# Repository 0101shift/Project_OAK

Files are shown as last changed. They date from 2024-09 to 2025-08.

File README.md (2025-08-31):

# ⌚️ Project OAK (Open Art Work)

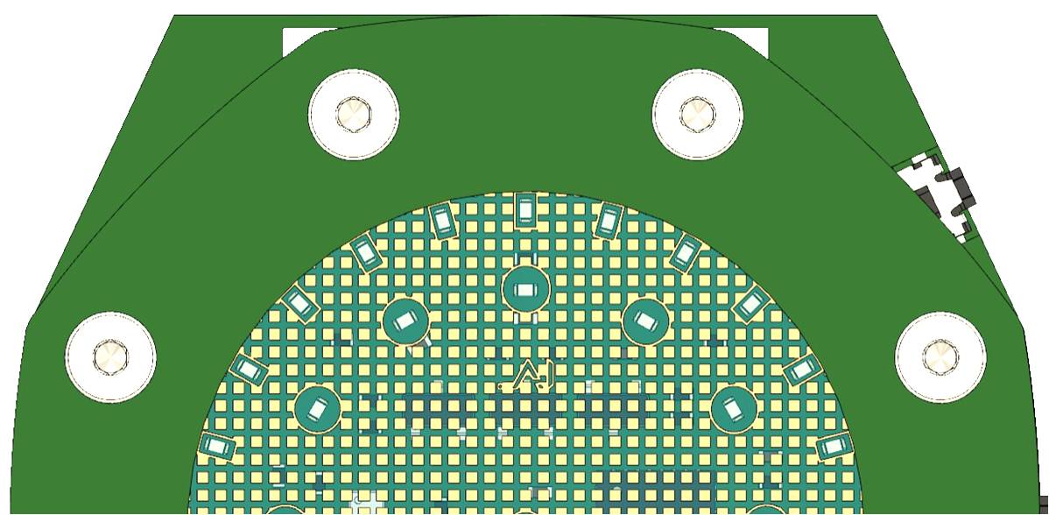
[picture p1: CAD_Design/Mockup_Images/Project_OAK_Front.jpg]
Project OAK

> *An approach to mimic analogue watch complications in a digital timepiece. One LED at a time.*

> ⚠️ **_Current Version: v0.1_**

> 📝 [_Version History_](Design/LLD_Design/README.md)
---

## 📁 Repository Overview

This repository contains all files related to **Project OAK**, including:

- Design files
- Datasheets
- Pin configuration sheet
- BOM (Bill of Materials)
- Source code and libraries
- Mechanical Integration files

📎 **Project OAK SCH and DSN files can be viewed on [CADLAB.io](https://cadlab.io/project/28412)**

---

## 📖 Project Overview

**Project_OAK** explores a different approach to designing digital timepieces that mimic the beauty and intricacy of **[mechanical watch complications](https://teddybaldassarre.com/blogs/watches/watch-complications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)**.

While building a digitalised analogue-style watch is fairly common, recreating some of the mechanical features in a purely digital watch is both challenging and exciting.

> Although current smartwatches offer these functions via complex hardware, my goal is to **implement them using simple hardware** with minimal processing power.

- To add to its uniqueness, the **entire watch will be constructed using stacked PCBs**, which is aimed to be modular and reconfigurable based on our needs.
- The watch is designed with multiple colours and solder finishes, giving it a true electronics-nerd feel.

---

## 🎲 How it Works

> "V0.1 / V0.2" come with a simple design to set and view the time. Here’s an infographic that shows the process

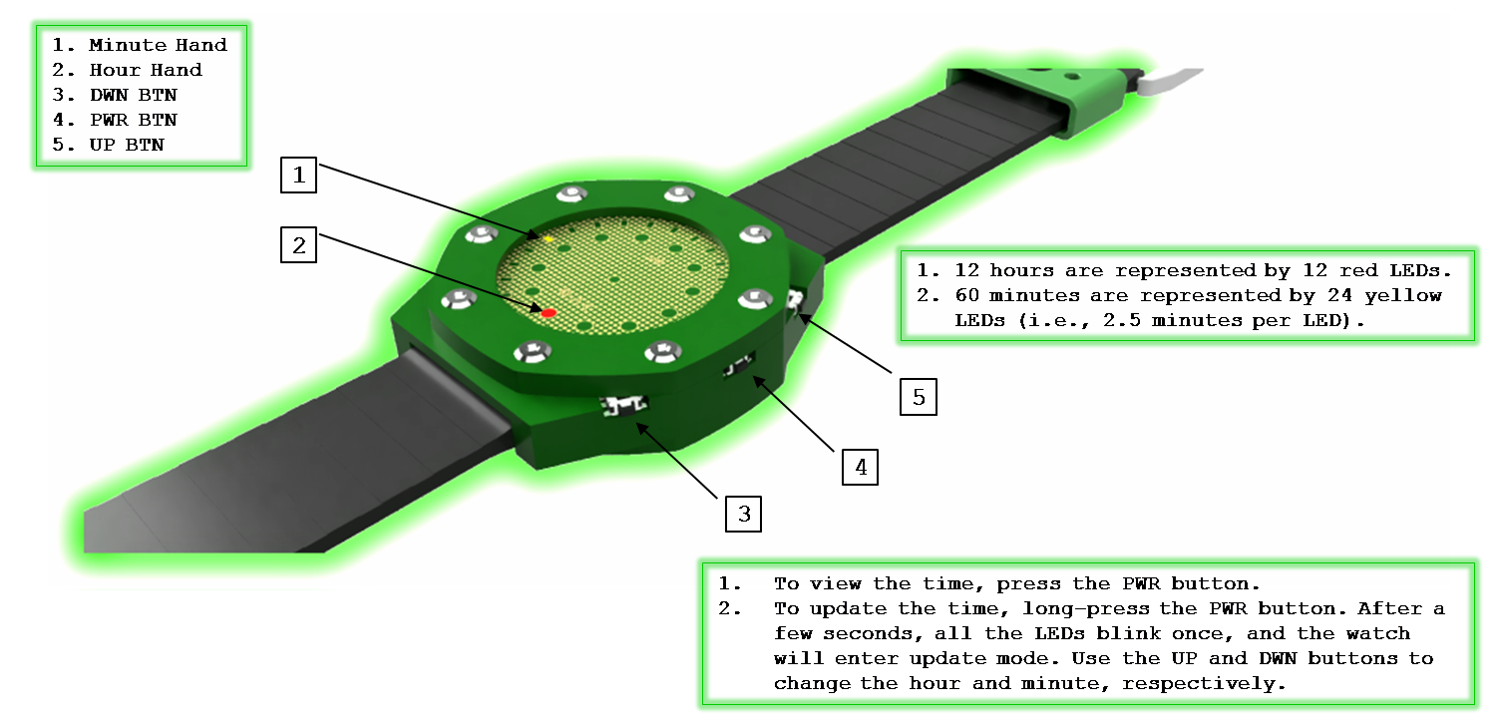
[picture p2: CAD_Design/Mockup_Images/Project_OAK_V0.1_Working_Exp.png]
V0.1 working


---

## 🔧 Initial Prototype

📌 **[Project_OAK_MAIN_BRD_V0.1 / V0.2](Design/LLD_Design/V0.1/Project_OAK_MAIN_BRD_V0.1_RTC_Change/Project_OAK_MAIN_BRD_V0.1.pdf) is an "engineering sample".**

The primary goal of these variants is to **test all available interfaces, validate battery performance, identify design flaws, and iterate for improvements**.

Consider this board a creative playground, push its limits and explore unique feature additions for the upcoming revision.

---

## 🚀 Down the line

Though the **initial version** of Project_OAK (V0.1 / V0.2) is just a simple watch featuring a **time display** using dual-tone LEDs,

> The Future versions shall include:
> - GMT
> - Minute Repeater (ambitious!)
> - Interactive sensors (Light, IMU, Temp, Step tracking, Buzzer, etc.)
> - Higher-density LED matrix for complex visuals.
> - Position tracking using GPS, LoRa, etc. (ambitious!)
> - Exploring Low-power MCUs for long-life operation.
> - Rechargeable battery option.
> - Solar panel integration for energy harvesting.
> - ...

---

## 💎 Mechanical Integration (v0.1)

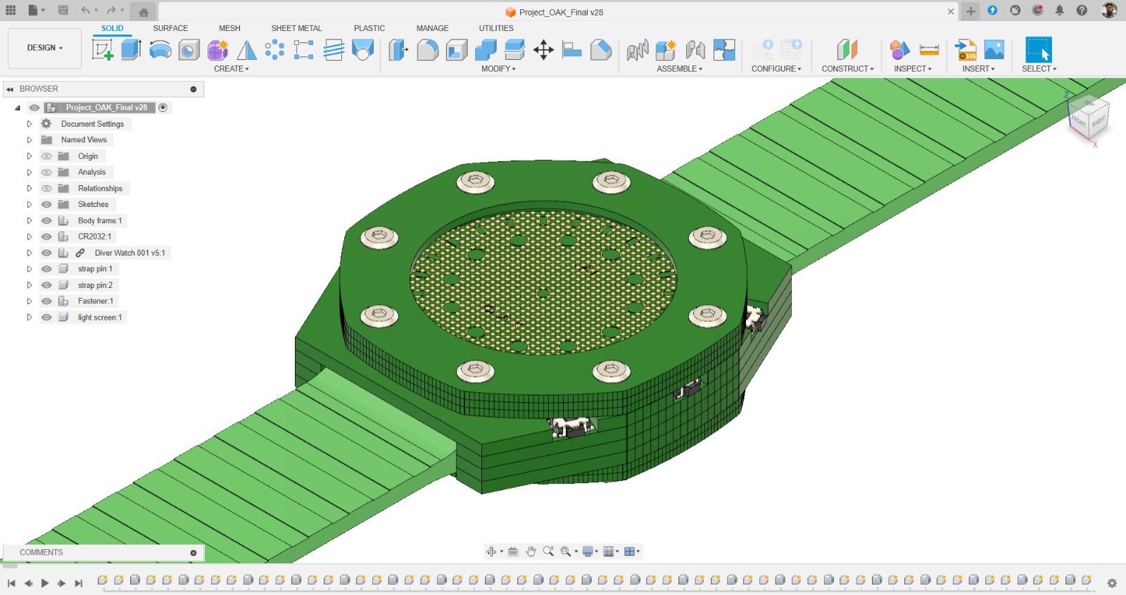
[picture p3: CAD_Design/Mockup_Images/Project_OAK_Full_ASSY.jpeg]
Initial Mockup


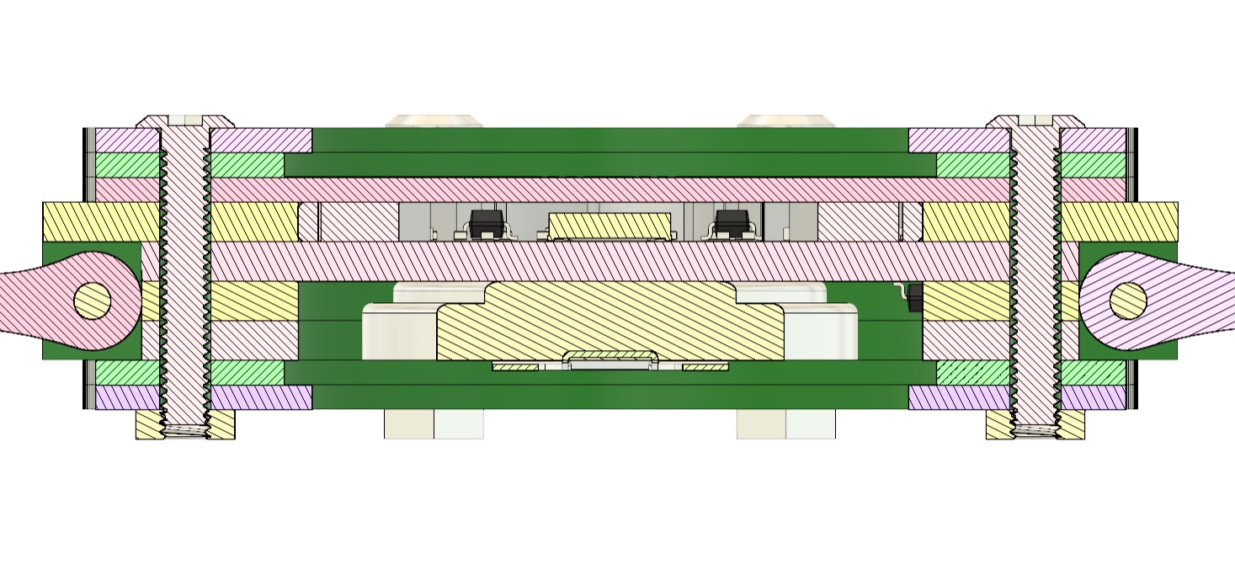
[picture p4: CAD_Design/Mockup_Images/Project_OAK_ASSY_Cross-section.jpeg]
Cross-section View


Exploded View

Exploded View

> *(These are the outputs from V0.1 variant. Design changes are expected in V0.2)*

---

## ⚙️ Getting Started

### 🔌 Programming the Board

The board can be programmed using the **Arduino IDE** via the ISP function. All the source code can be found in [ProjectOAK/codes](Codes) folder. 

#### 📝 Requirements:
- Arduino UNO/MINI/NANO/MEGA as ISP programmer
- ICSP connection to the Main Board (test points on the bottom side)

#### 💡 ICSP Programming Notes:
- ICSP pins are exposed via **Test Points** arranged in 2.4mm pitch 2x3 connector style
- Either mount **male headers** or directly solder wires for programming
- Board supports **two power options**:
  - `3V Coin Cell (default)`
  - `EXT_3V3_IN` via ICSP (requires mounting resistor R1, which is **DNI by default**)

### ⚡ Arduino IDE Settings

> - Refer to this GitHub repo on how to burn the Bootloader and how to flash code through Arduino IDE [MiniCore](https://github.com/MCUdude/MiniCore)
> - When programming the MAIN_BRD, update the ARDUINO IDE settings as shown below.

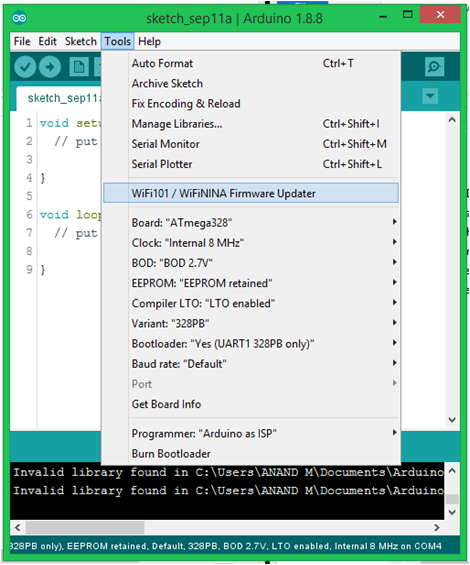
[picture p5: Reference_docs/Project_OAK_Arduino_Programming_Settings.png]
Arduino IDE settings


#### ❤️‍🔥 Let me know what you think of this project. I'd love to hear your thoughts!

### ✨ Happy Designing!

---

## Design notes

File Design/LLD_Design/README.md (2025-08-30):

# 📚 Version History

## 🔮 V0.2 (Engineering Sample2 - Planned)
- Button circuit connectivity update
- Remove the transistor configuration from the LED matrix directly. Direct connection is simple.
- Battery monitoring circuit implementation (possibly).
- Push button components to be moved towards the inner circle to avoid mechanical collision.
- Top Silk graphics to be removed from the main board.
- Main board & BOT cavity PCB dimension to be increased in Y-direction, to match the STARP V0 board dimension
- 0E to be replaced with solder-jumpers in the LED matrix section
- DNPed MCU UART resistors
  
## 🔰 V0.1 (Engineering Sample - WIP)
- RTC changed from RX8130CE to RV-8263-C7.
- Addressed design issues with rework on the main board. Rework is documented in: [Project_OAK_MAIN_BRD_V0.1_Rework](Reworks/V0.1/README.md). 
- Cell voltage monitoring (along with LED indication) is not implemented in V0.1. Planned for V0.2
- Final testing in progress.

 <div style="background-color:#ffe6e6; padding:10px; border-radius:6px;">
⚠️ <b>Caution:</b> Other layers, except the Main Board, are reused from V0
</div>

## 🚫 V0 (Initial Design - Unreleased)
- Initial board design consists of ATmega328PB MCU, RX8130CE RTC, 36 LEDs (12H + 24M) & 2032 coin cell holder  
- The design was not released for fabrication due to a change in the RTC module.

---

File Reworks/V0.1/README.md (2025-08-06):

# 🔧 Project OAK MAIN BRD V0.1 Rework

This document outlines the necessary fixes, design limitations, and manual rework instructions for **Version 0.1** of the main board.

## 📋 Includes:
- Design errors identified during testing
- Workarounds and hardware patches
- Recommended changes for future revisions

> ⚠️ These instructions are critical if you're testing or building with `Project_OAK_MAIN_BRD_V0.1`.

---

## ❌ Design Errors

- The **BC547 transistor** symbol used in the design (V0 / V0.1) was of **TO-92 type**, while the actual **PCB footprint was for SOT-type**. This caused pin mismatch and made the footprint incompatible.
  
- The **push-button connection** was incorrect. It was connected between **pin 1 & pin 2** in the schematic, whereas the correct connection should be **between pin 1 & pin 3**. This made the switch unresponsive as pin 2 was shorted between GND and VCC via the 10k resistor.

---

## 🔶 Workaround for Transistor

- Since the BC547 pinout issue can't be resolved easily on the PCB, better to:
  - **Remove the transistor**, and  
  - **Short the Base and Emitter pins**.  
    This gives direct control of the LEDs to the MCU, and the firmware has been adjusted accordingly.

> 🔧 Additionally:
> - Remove the **resistor connected to the Collector pin**, as it will be left floating after the transistor is removed.
> - Reduce the **Base resistor value to 560Ω or less**, allowing sufficient current flow from the LEDs to the MCU.

---

## 🔶 Workaround for Push-Button

To make the push-button functional:
- Remove the **external pull-up resistor** (the internal pull-up is sufficient).
- Carefully **cut the trace between pin 2 and GND** to isolate pin 2. *(This can be tricky but is necessary.)*
- Connect **pin 3 to GND** using a short jumper wire.

---

## ✔️ V0.1 Rework Instructions

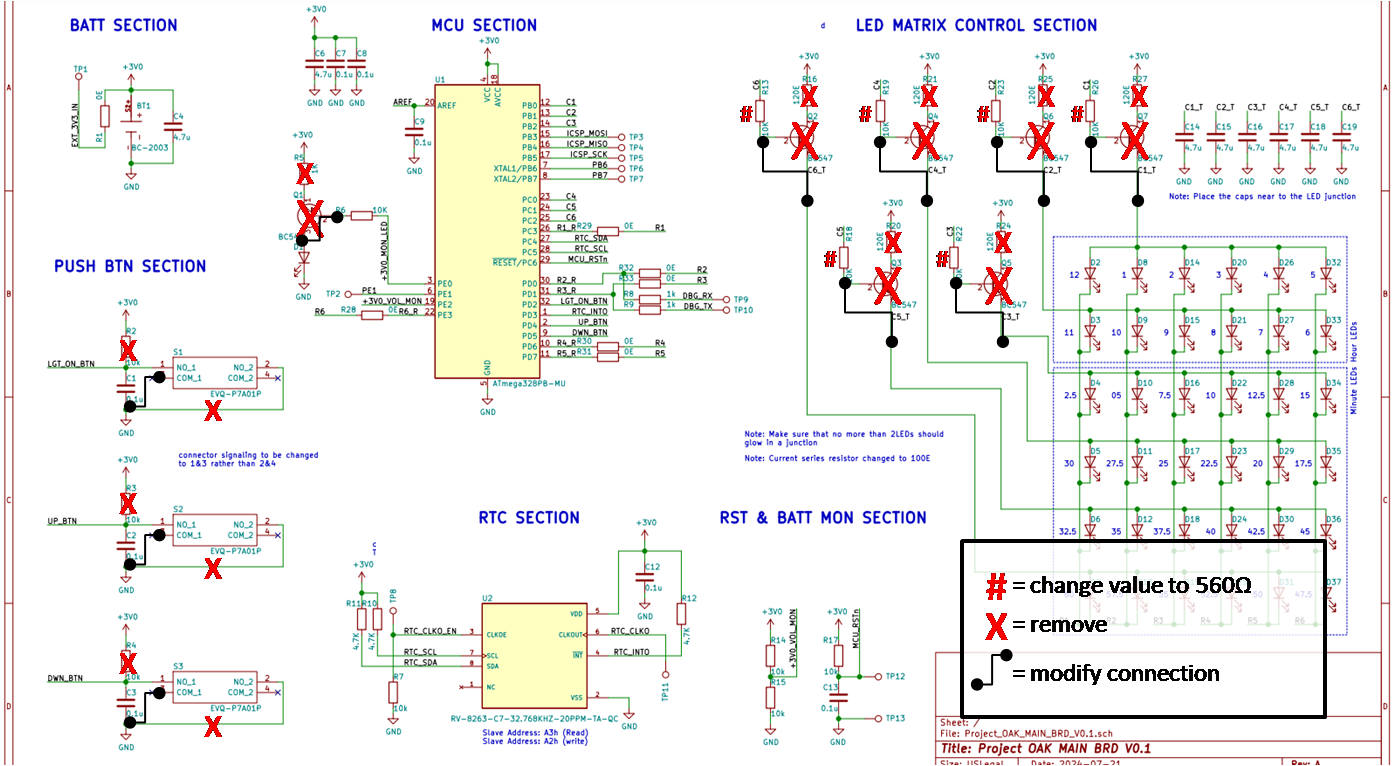
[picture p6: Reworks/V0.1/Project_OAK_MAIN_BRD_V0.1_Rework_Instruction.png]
Project_OAK_MAIN_BRD_V0.1_Rework


---

## 📌 Recommendations for Future Revisions

- **Remove the transistors** in the LED section entirely:
  - The LED matrix draws low current and can be driven directly by the MCU.
  - This also helps reduce BOM cost and simplifies the layout.
  
- **Double-check all component footprints and connections** to avoid similar pin mismatch issues.

---

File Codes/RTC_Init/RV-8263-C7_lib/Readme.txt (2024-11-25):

Place the lib files present in src folder into Arduino libraries 
folder before compiling the code

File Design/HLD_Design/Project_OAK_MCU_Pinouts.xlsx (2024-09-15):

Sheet: Pin_Mapping
ATMEGA328PB-MU Pin mapping |  |  |  |  |  |  |  |  | Available GPIOs: | 27
S. No | Pin Name | Pin Type | Pin Functions |  |  |  | Functions Assigned | Destination | Used GPIOs: | 24
 |  |  | Default | Alt1 | Alt2 | Alt3 |  |  | Excess GPIOs: | 3
1 | PD[3] | GPIO | IO | INT1 | OC2B |  | INTERRUPT | RTC
2 | PD[4] |  | IO | T0 |  |  | INPUT | BTN
3 | PE[0] |  | IO | ACO | ICP4 | SDA1 | IO | BAT MON LED
4 | VCC | POWER
5 | GND
6 | PE[1] | GPIO | IO | T4 | SCL1 |  | IO | Future use
7 | PB[6] | CLOCK |  | XTAL1/TOSC1
8 | PB[7] |  |  | XTAL2/TOSC2
9 | PD[5] | GPIO | IO | OC0B / T1 |  |  | INPUT | BTN
10 | PD[6] |  |  | AIN0 | OC0A |  | IO | LED MTRX CTRLx
11 | PD[7] |  |  | AIN1
12 | PB[0] |  |  | CLKO | ICP1
13 | PB[1] |  |  | OC1A
14 | PB[2] |  |  | OC1B | SS0
15 | PB[3] |  |  | OC2A | TXD1 | MOSI0 | SPI | ICSP
16 | PB[4] |  |  | RXD1 | MISO0
17 | PB[5] |  |  | XCK1 | SCK0
18 | AVCC | POWER
19 | PE[2] | GPIO | IO | ADC6 | ICP3 | SS1 | ADC | BAT VOL MON
20 | AREF | ANALOG POWER
21 | GND | POWER
22 | PE[3] | GPIO | IO | ADC7 | T3 | MOSI1 | IO | LED MTRX CTRLx
23 | PC[0] |  |  | ADC0 | MISO1
24 | PC[1] |  |  | ADC1 | SCK1
25 | PC[2] |  |  | ADC2
26 | PC[3] |  |  | ADC3
27 | PC[4] |  |  | ADC4 | SDA0 |  | I2C | RTC
28 | PC[5] |  |  | ADC5 | SCL0
29 | PC[6] | RESET
30 | PD[0] | GPIO | IO | OC3A | RXD0 |  | UART / IO | LED MTRX CTRLx + UART DEBUG
31 | PD[1] |  |  | OC4A | TXD0
32 | PD[2] |  |  | INT0 | OC3B / OC4B |  | INTERRUPT | BTN

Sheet: LED_Mapping
WATCH DIAL LED Mapping
S. No | Row | Column | Row Pin | Column Pin | LED Type | LED Value
1 | C1 | R1 | PB0 | PC3 | Hour | 12
2 | C1 | R2 | PB0 | PD0 | Hour | 1
3 | C1 | R3 | PB0 | PD1 | Hour | 2
4 | C1 | R4 | PB0 | PD6 | Hour | 3
5 | C1 | R5 | PB0 | PD7 | Hour | 4
6 | C1 | R6 | PB0 | PE3 | Hour | 5
7 | C2 | R1 | PB1 | PC3 | Hour | 11
8 | C2 | R2 | PB1 | PD0 | Hour | 10
9 | C2 | R3 | PB1 | PD1 | Hour | 9
10 | C2 | R4 | PB1 | PD6 | Hour | 8
11 | C2 | R5 | PB1 | PD7 | Hour | 7
12 | C2 | R6 | PB1 | PE3 | Hour | 6
13 | C3 | R1 | PB2 | PC3 | Minute | 2.5
14 | C3 | R2 | PB2 | PD0 | Minute | 5
15 | C3 | R3 | PB2 | PD1 | Minute | 7.5
16 | C3 | R4 | PB2 | PD6 | Minute | 10
17 | C3 | R5 | PB2 | PD7 | Minute | 12.5
18 | C3 | R6 | PB2 | PE3 | Minute | 15
19 | C4 | R1 | PC0 | PC3 | Minute | 30
20 | C4 | R2 | PC0 | PD0 | Minute | 27.5
21 | C4 | R3 | PC0 | PD1 | Minute | 25
22 | C4 | R4 | PC0 | PD6 | Minute | 22.5
23 | C4 | R5 | PC0 | PD7 | Minute | 20
24 | C4 | R6 | PC0 | PE3 | Minute | 17.5
25 | C5 | R1 | PC1 | PC3 | Minute | 32.5
26 | C5 | R2 | PC1 | PD0 | Minute | 35
27 | C5 | R3 | PC1 | PD1 | Minute | 37.5
28 | C5 | R4 | PC1 | PD6 | Minute | 40
29 | C5 | R5 | PC1 | PD7 | Minute | 42.5
30 | C5 | R6 | PC1 | PE3 | Minute | 45
31 | C6 | R1 | PC2 | PC3 | Minute | 0
32 | C6 | R2 | PC2 | PD0 | Minute | 57.5
33 | C6 | R3 | PC2 | PD1 | Minute | 55
34 | C6 | R4 | PC2 | PD6 | Minute | 52.5
35 | C6 | R5 | PC2 | PD7 | Minute | 50
36 | C6 | R6 | PC2 | PE3 | Minute | 47.5

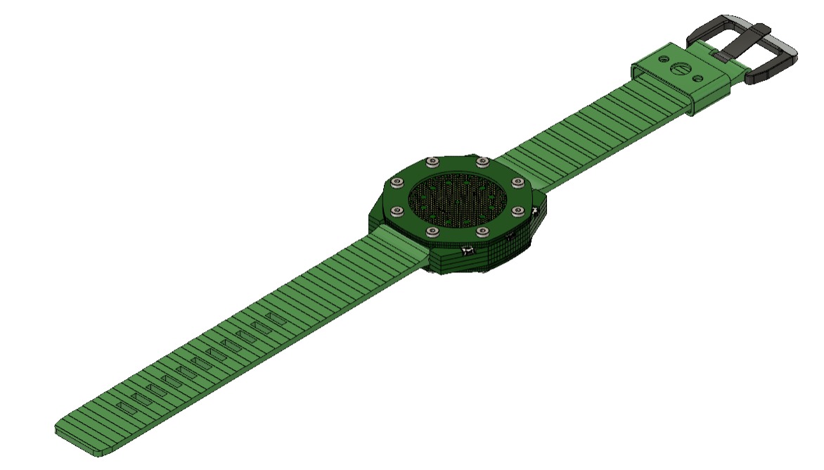
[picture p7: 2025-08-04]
CAD_Design/Mockup_Images/Project_OAK_Full_ASSY_1.jpeg

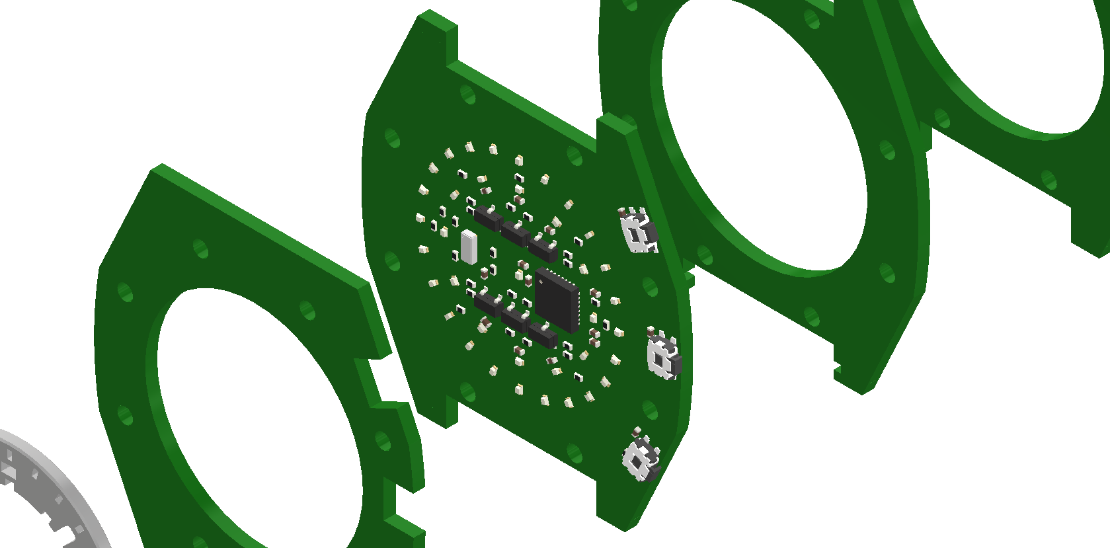
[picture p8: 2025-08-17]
CAD_Design/Mockup_Images/Project_OAK_Exploded_view.png

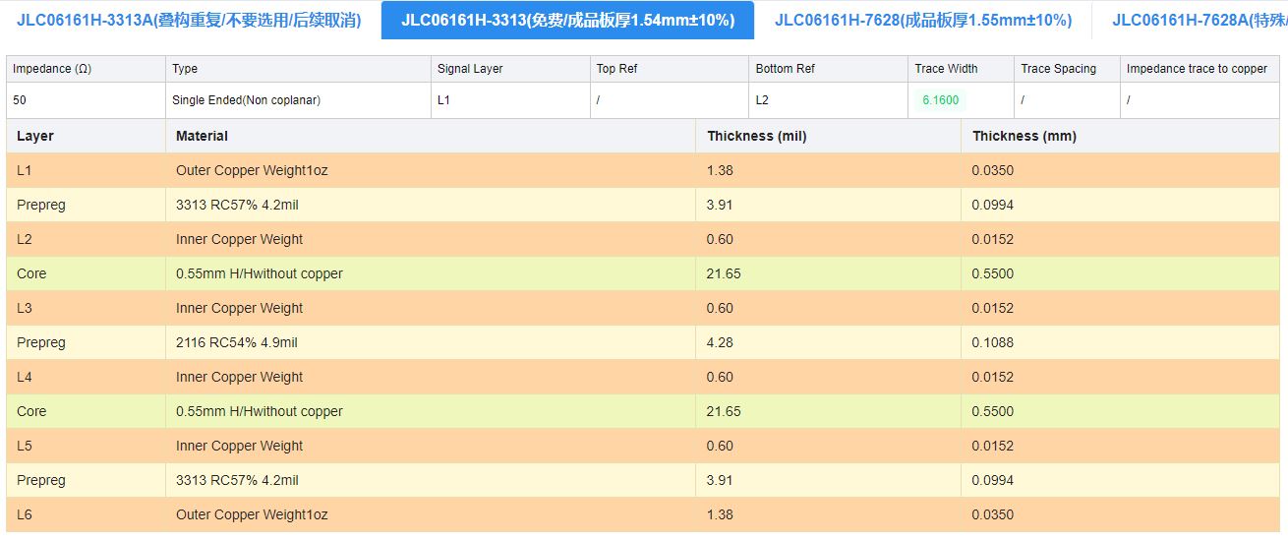
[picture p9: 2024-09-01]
CAD_Design/PCB_CAD/6L_JLCPCB_Stackup.JPG

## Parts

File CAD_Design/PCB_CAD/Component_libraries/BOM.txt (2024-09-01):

1. DS3231MZ+TRL / RX8130CE / RX8111CE
 / RV-8263-C7-32.768KHZ-20PPM-TA-QC -> RTC module
2. PKLCS1212E4001-R1 -> buzzer
3. BC-2003 -> SMD battery holder
4. EVQ-P7A01P -> Tactle switch
5. ATMEGA328P-MMHR / ATMEGA328PB-MNR / ATMEGA328PB-MU / ATMEGA328PB-AU-> MCU

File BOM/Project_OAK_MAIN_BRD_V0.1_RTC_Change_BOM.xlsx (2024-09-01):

Qty | Ref. Desg. | Value | Description | MFR PN | MFR | JLCPCB PN | Footprint | Assembly Instruction
1 | BT1 | BC-2003 |  |  |  |  | Battery:BAT_BC-2003 | DNP
8 | C1, C2, C3, C7, C8, C9, C12, C13 | 0.1u | 16V 100nF X7R ±10% 0402 Multilayer Ceramic Capacitors MLCC - SMD/SMT ROHS | GCM155R71C104KA55J | Murata Electronics | C2655418 | Capacitor_SMD:C_0402_1005Metric
1 | C4 | 4.7u |  |  |  |  |  | DNP
7 | C6, C14, C15, C16, C17, C18, C19 | 4.7u | 6.3V 4.7uF X5R ±20% 0402 Multilayer Ceramic Capacitors MLCC - SMD/SMT ROHS | C1005X5R0J475MTJ00E | TDK | C23687 | Capacitor_SMD:C_0402_1005Metric
25 | D1, D4, D5, D6, D7, D10, D11, D12, D13, D16, D17, D18, D19, D22, D23, D24, D25, D28, D29, D30, D31, D34, D35, D36, D37 | Yellow LED | Yellow 592nm LED Indication - Discrete 2V 0402 (1005 Metric) | LTST-C281KSKT | Lite-On Inc. | C913108 | LED_SMD:LED_0402_1005Metric
12 | D2, D3, D8, D9, D14, D15, D20, D21, D26, D27, D32, D33 | Red LED | Red 0402 LED Indication - Discrete ROHS | 16-213/R6C-AQ2R2B/3T | Everlight Elec | C264407 | LED_SMD:LED_0402_1005Metric
7 | Q1, Q2, Q3, Q4, Q5, Q6, Q7 | BC547 |  |  |  |  | Package_TO_SOT_SMD:SOT-23 | DNP
7 | R1, R28, R29, R30, R31, R32, R33 | 0E |  |  |  |  | Resistor_SMD:R_0402_1005Metric | DNP
1 | R1 | 0E |  |  |  |  | Resistor_SMD:R_0402_1005Metric | DNP
14 | R2, R3, R4, R6, R7, R14, R15, R17, R13, R18, R19, R22, R23, R26 | 10k | 63mW Thick Film Resistors ±100ppm/℃ ±5% 10kΩ 0402 Chip Resistor | CR0402J10K0Q10Z | Ever Ohms Tech | C881063 | Resistor_SMD:R_0402_1005Metric
3 | R5, R8, R9 | 1K |  |  |  |  | Resistor_SMD:R_0402_1005Metric | DNP
3 | R10, R11, R12 | 4.7K | 62.5mW ±1% 4.7kΩ 0402 Chip Resistor - Surface Mount ROHS | RMC04024K7FN | TyoHM | C270129 | Resistor_SMD:R_0402_1005Metric
6 | R16, R20, R21, R24, R25, R27 | 100E | 62.5mW Thick Film Resistors 50V ±100ppm/℃ ±0.5% 100Ω 0402 Chip Resistor - Surface Mount ROHS | RM04DTN1000 | TA-I Tech | C187947 | Resistor_SMD:R_0402_1005Metric
3 | S1, S2, S3 | EVQ-P7A01P | Black Side Tactile Switch, Single Pole Single Throw (SPST) 50 mA @ 12 V dc 1.7mm | EVQ-P7A01P | Panasonic | EVQP7A01P | Button_Switch_SMD:EVQP7J01P
1 | U1 | ATmega328PB-MU | 32KB 1.8V~5.5V AVR 2KB 20MHz FLASH 27 QFN-32-EP(5x5) Microcontrollers (MCU/MPU/SOC) ROHS | ATmega328PB-MU | Microchip | C967933 | Package_DFN_QFN:QFN-32-1EP_5x5mm_P0.5mm_EP3.1x3.1mm
1 | U2 | RV-8263-C7-32.768KHZ-20PPM-TA-QC | I2C SON-8(1.5x3.2) Real Time Clocks ROHS | RV-8263-C7-32.768KHZ-20PPM-TA-QC | Micro Crystal | C5138246 | Crystal:RV-8263-C7-32.768KHZ-20PPM-TA-QC

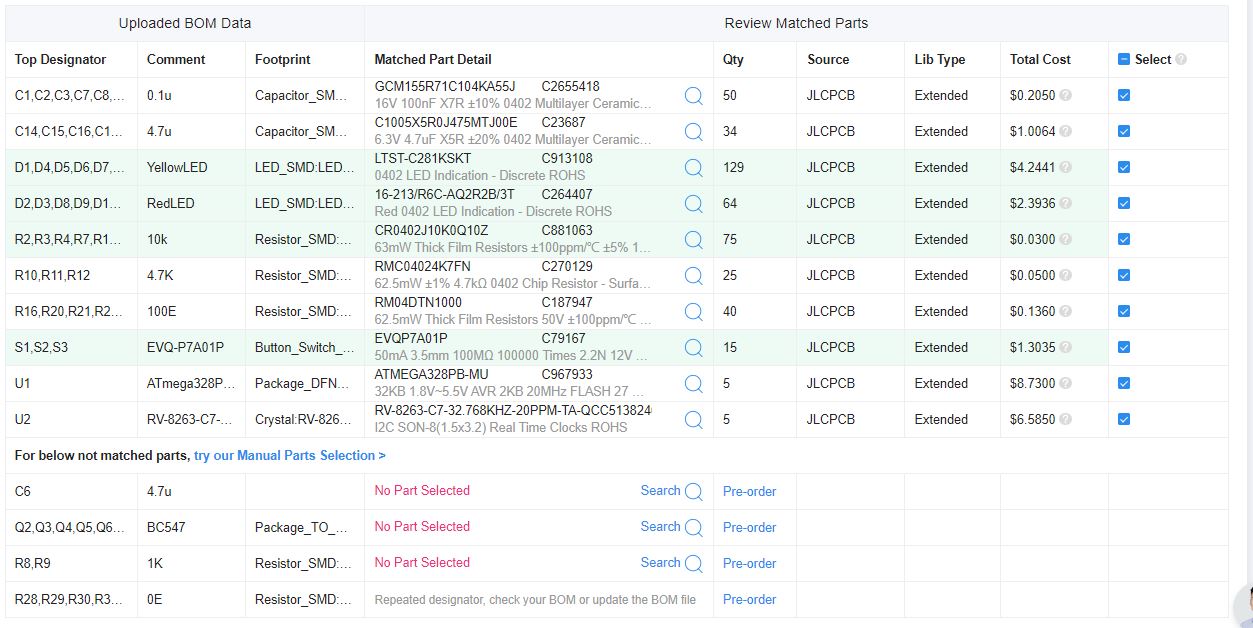
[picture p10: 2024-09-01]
BOM/Project_OAK_MAIN_BRD_V0.1_RTC_Change_JLCPCB_Final_BOM.JPG

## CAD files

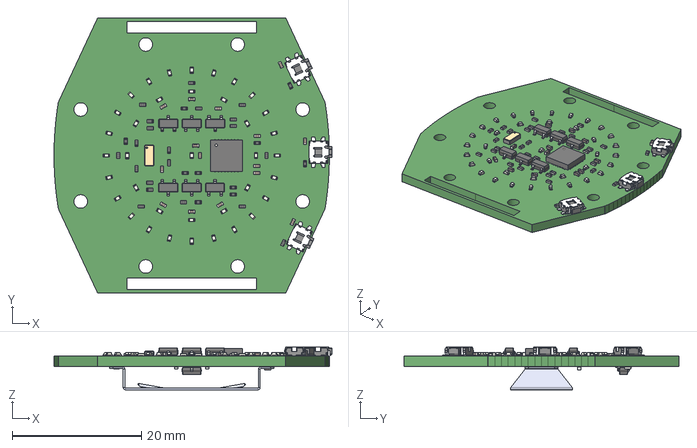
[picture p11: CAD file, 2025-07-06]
Design/LLD_Design/V0.1/Project_OAK_MAIN_BRD_V0.1_RTC_Change/Project_OAK_MAIN_BRD_V0.1.step
43.0 x 42.6 x 6.59 mm

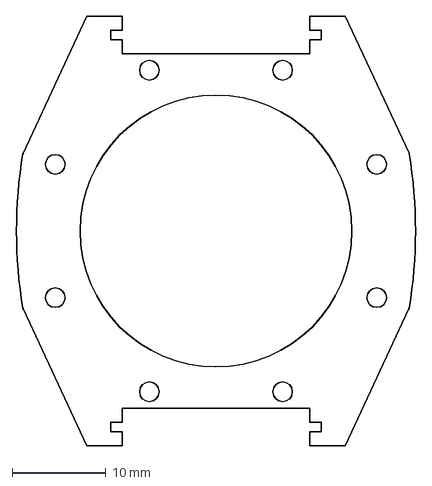
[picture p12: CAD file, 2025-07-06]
CAD_Design/Mechanical_CAD/PROJECT_OAK_BOT_STRAP.dxf
42.6 x 45.8 mm

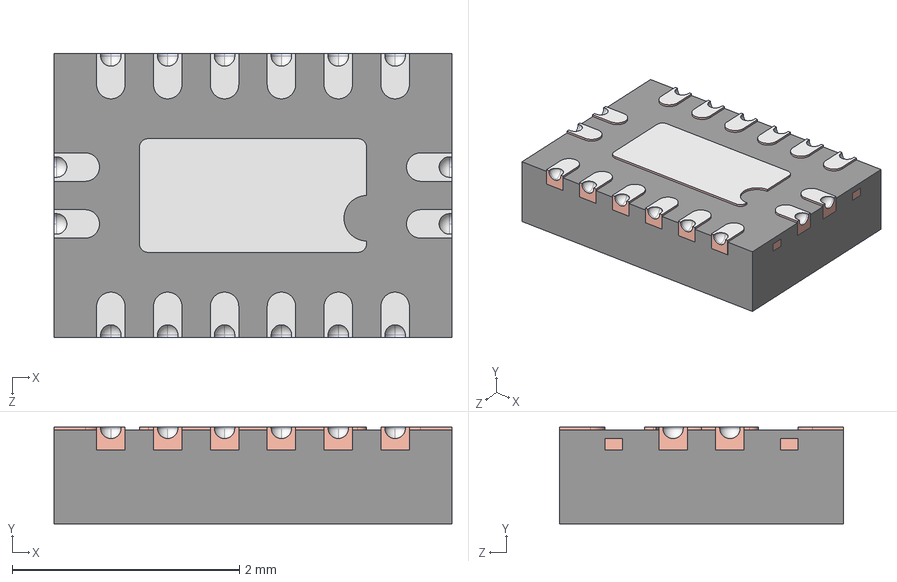
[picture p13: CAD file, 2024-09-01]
CAD_Design/PCB_CAD/Component_libraries/74CBTLV3257BQ,115/3D/74CBTLV3257BQ,115.stp
3.50 x 0.85 x 2.50 mm
SOT763-1 LF
SOT763-1 Mold Body

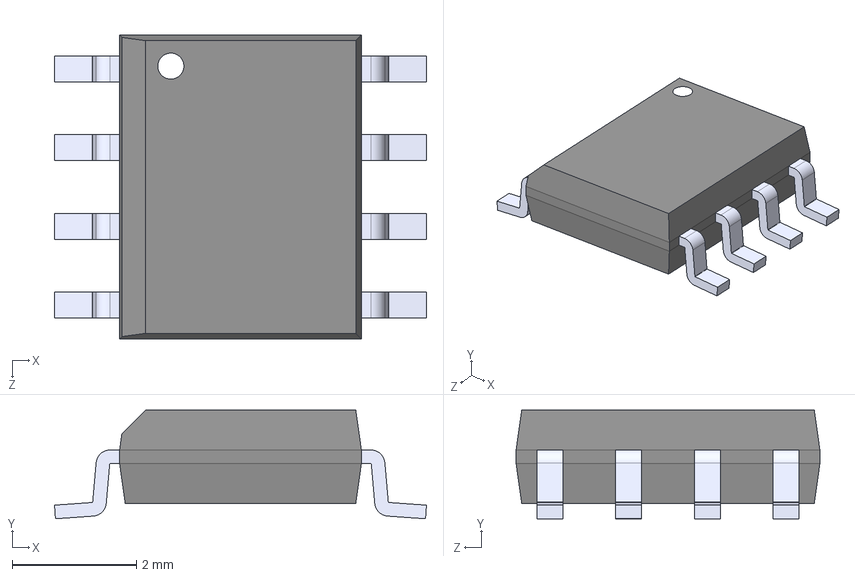
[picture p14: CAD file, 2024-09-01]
CAD_Design/PCB_CAD/Component_libraries/DS3231MZ_TRL/DS3231MZ_TRL.step
6.00 x 1.75 x 4.90 mm

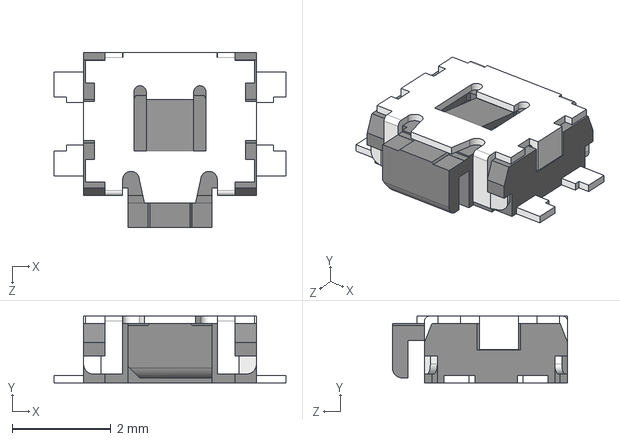
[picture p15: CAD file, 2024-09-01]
CAD_Design/PCB_CAD/Component_libraries/EVQ-P7A01P/3D/EVQ-P7A01P.stp
4.70 x 1.35 x 3.55 mm

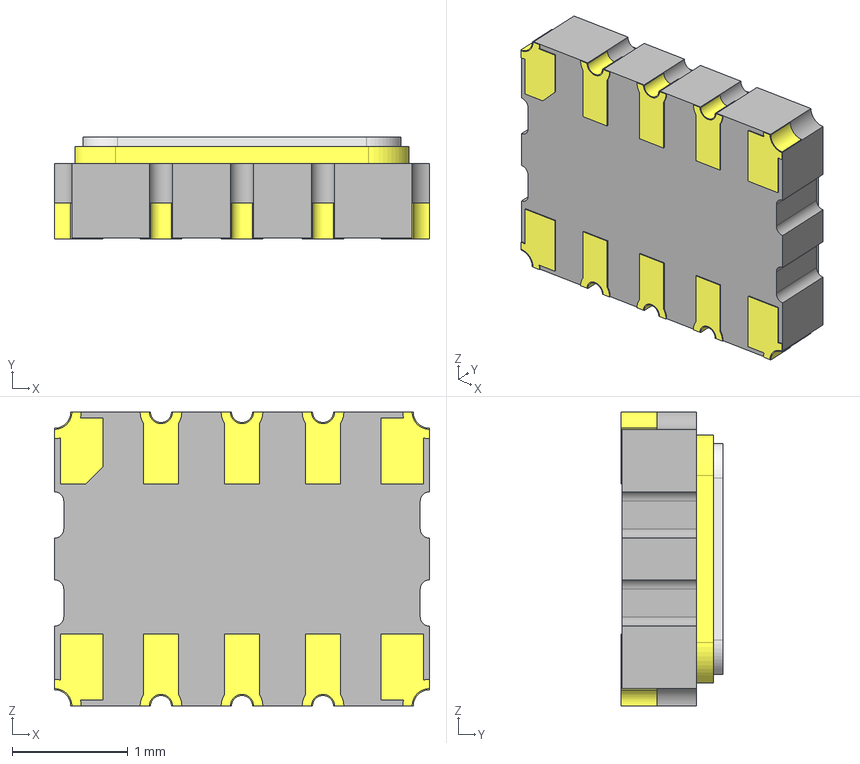
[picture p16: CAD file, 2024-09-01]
CAD_Design/PCB_CAD/Component_libraries/RX8130CE/RX8130CE.stp
3.24 x 0.88 x 2.54 mm
CERAMIC_1_1_2
____-______O__1_6__1_1_2
____-______O__1_5__1_1_2
____-______O__1_10__1_1_2
____-______O__1_7__1_1_2
____-______O__1_3__1_1_2
____-______O__1_4__1_1_2
____-______O__1_1__1_1_2
____-______O__1_2__1_1_2
____-______O__1_9__1_1_2
____-______O__1_8__1_1_2
SRING_1_1_2
LID0001_1_1_2

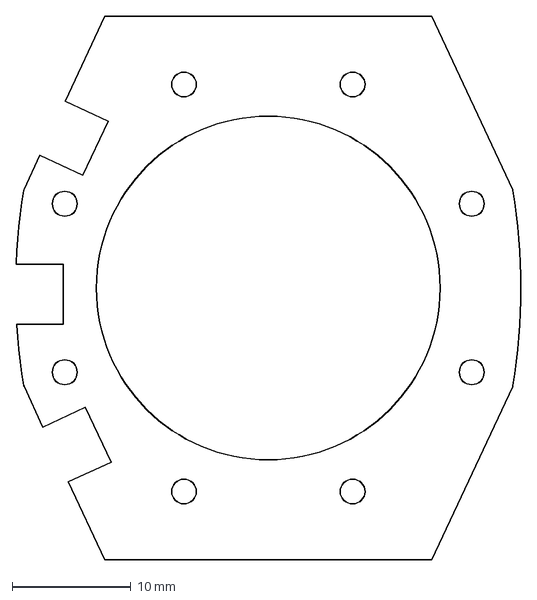
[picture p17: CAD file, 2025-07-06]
CAD_Design/Mechanical_CAD/PROJECT_OAK_TOP_LED_CAVITY.dxf
42.6 x 45.8 mm

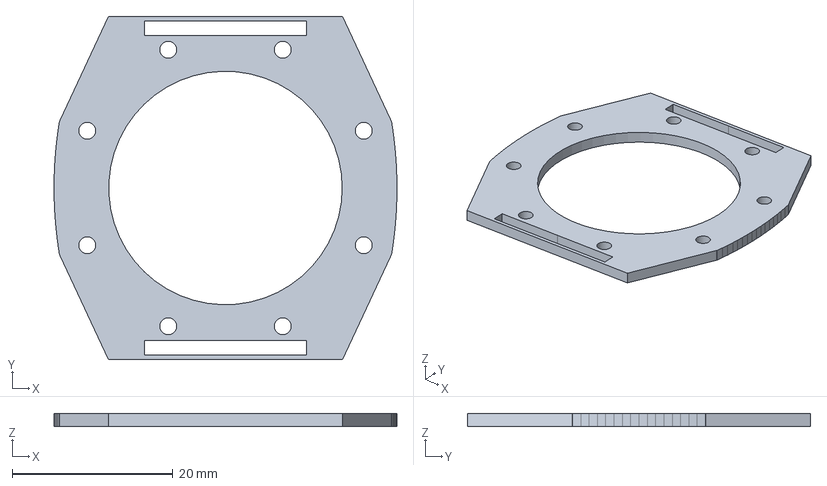
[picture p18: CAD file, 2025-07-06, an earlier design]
Design/LLD_Design/V0/Project_OAK_BOT_CAVITY_V0/Project_OAK_BOT_CAVITY_V0.step
42.6 x 42.6 x 1.60 mm

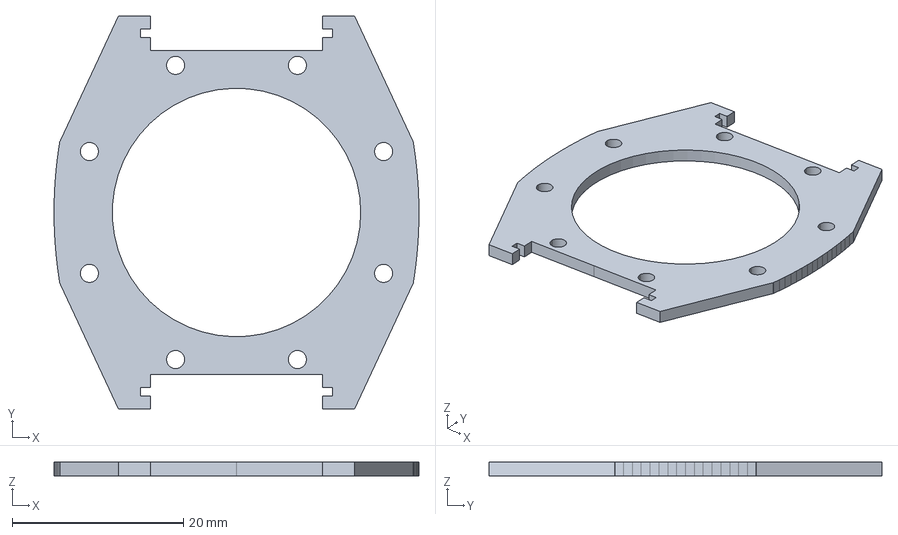
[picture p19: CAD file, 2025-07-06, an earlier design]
Design/LLD_Design/V0/Project_OAK_BOT_STRAP_V0/Project_OAK_BOT_STRAP_V0.step
42.6 x 45.8 x 1.60 mm

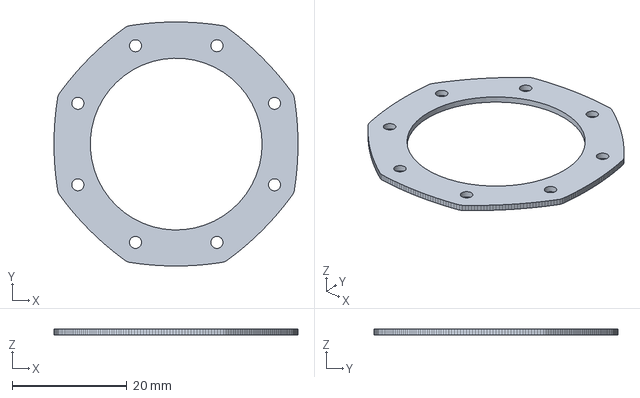
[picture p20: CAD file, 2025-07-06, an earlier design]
Design/LLD_Design/V0/Project_OAK_HEX_COVER_INNER_V0/Project_OAK_HEX_COVER_INNER_V0.step
42.6 x 42.6 x 1.00 mm

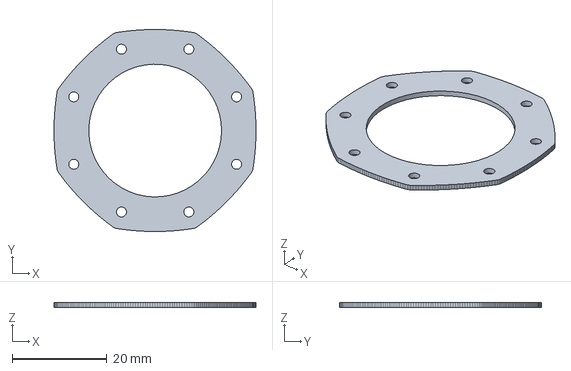
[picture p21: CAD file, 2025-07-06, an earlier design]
Design/LLD_Design/V0/Project_OAK_HEX_COVER_OUTER_V0/Project_OAK_HEX_COVER_OUTER_V0.step
42.6 x 42.6 x 1.00 mm

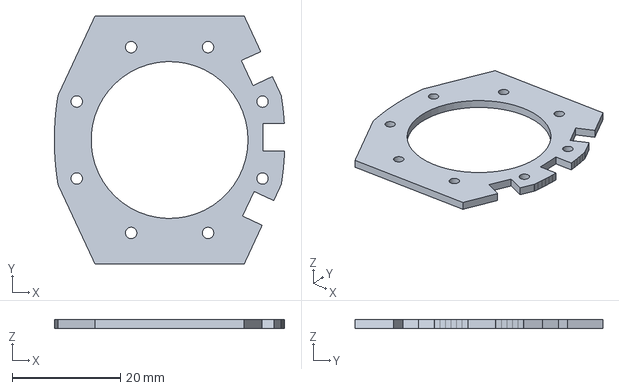
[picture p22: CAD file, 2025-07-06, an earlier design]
Design/LLD_Design/V0/Project_OAK_TOP_LED_CAVITY_V0/Project_OAK_TOP_LED_CAVITY_V0.step
42.6 x 45.8 x 1.60 mm

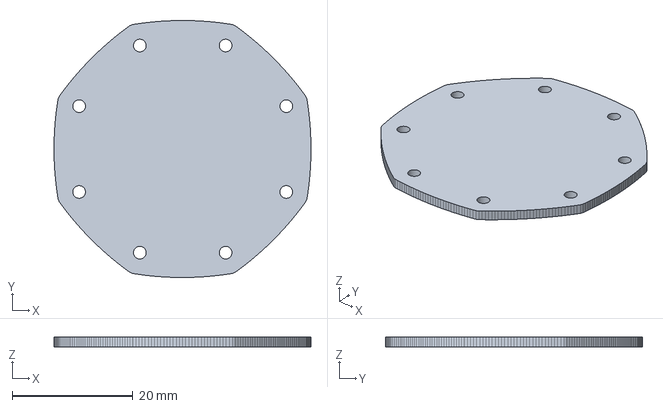
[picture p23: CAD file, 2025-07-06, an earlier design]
Design/LLD_Design/V0/Project_OAK_WATCH_DIAL_V0/Project_OAK_WATCH_DIAL_V0.step
42.6 x 42.6 x 1.60 mm

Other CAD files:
CAD_Design/PCB_CAD/Component_libraries/74CBTLV3257BQ,115/Allegro/74hct595bq115.psm
CAD_Design/PCB_CAD/Component_libraries/74CBTLV3257BQ,115/DEHDL/74cbtlv3257bq_115/chips/chips.prt
CAD_Design/PCB_CAD/Component_libraries/EVQ-P7A01P/Allegro/evqp7j01p.psm
CAD_Design/PCB_CAD/Component_libraries/EVQ-P7A01P/DEHDL/evq_p7a01p/chips/chips.prt

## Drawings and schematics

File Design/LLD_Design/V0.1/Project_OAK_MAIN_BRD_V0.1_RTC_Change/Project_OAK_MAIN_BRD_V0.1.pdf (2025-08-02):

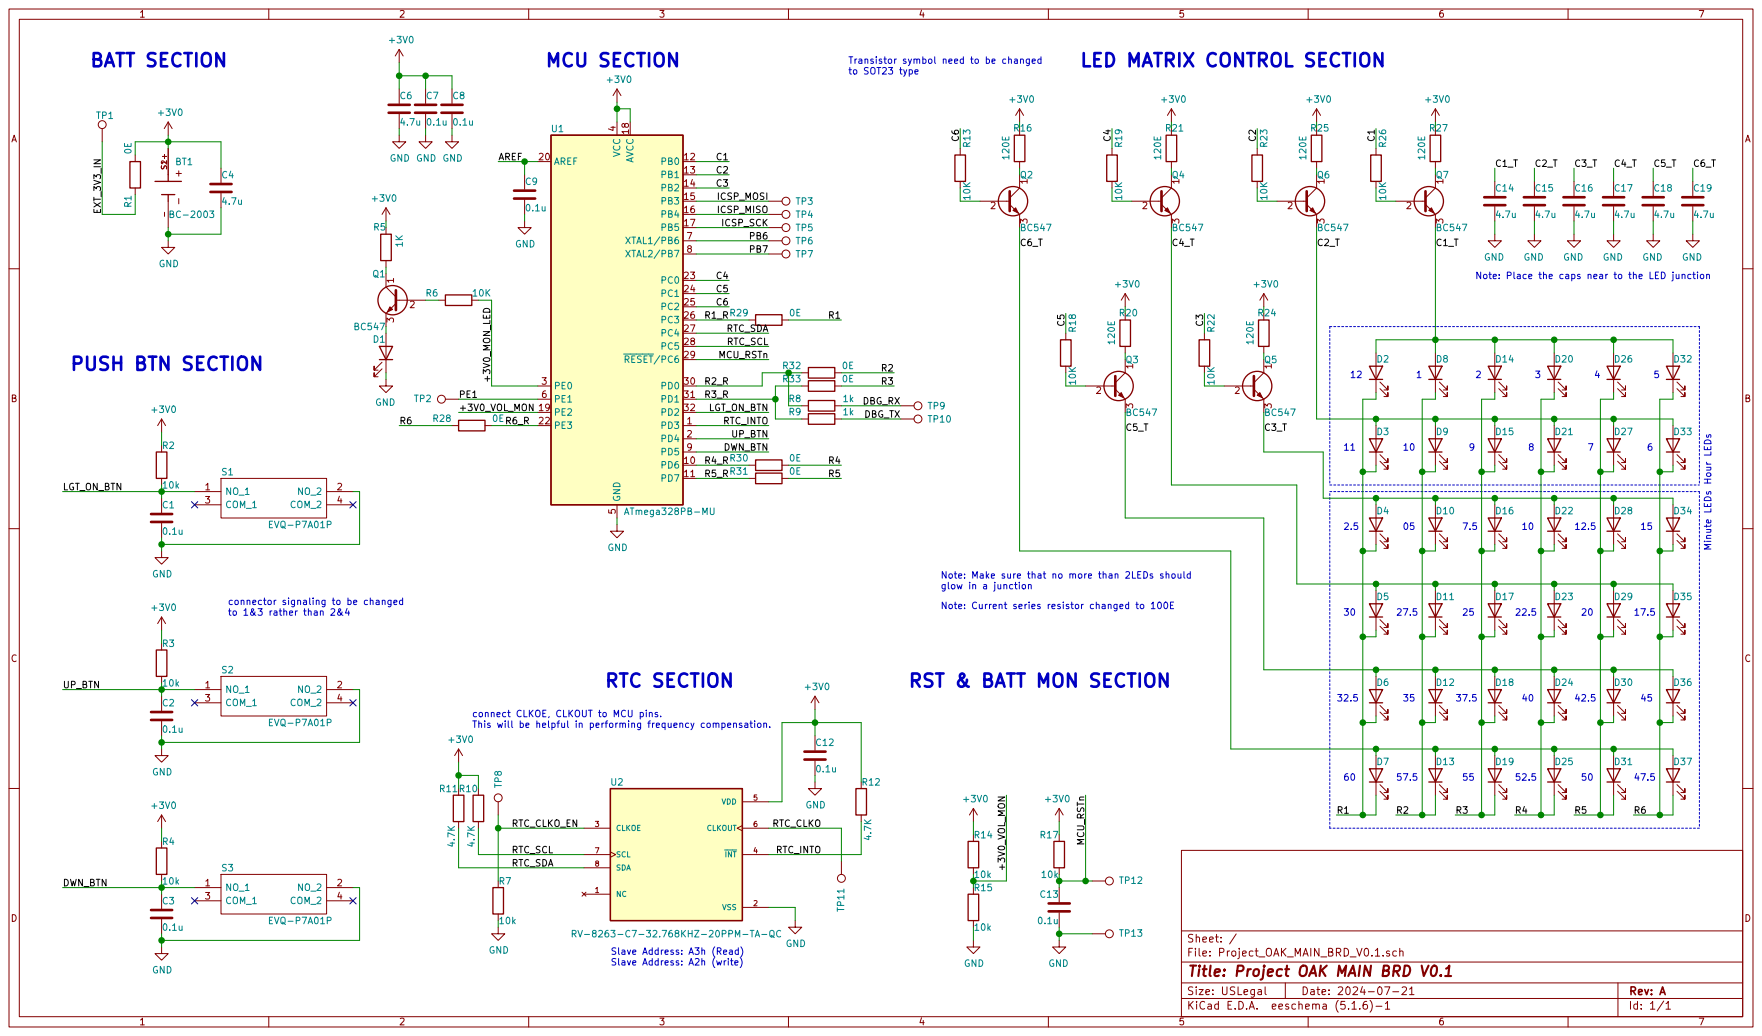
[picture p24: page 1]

LED MATRIX CONTROL SECTION

Transistor symbol need to be changed
to SOT23 type

connector signaling to be changed

60 32.5 | 57.5 | 55 RST & BATT MON SECTION

connect CLKOE, CLKOUT to MCU pins.

D Date: 2024-07-21 KiCad E.D.A. eeschema (5.1.6)-1
File: Project_OAK_MAIN_BRD_V0.1.sch Sheet: /
Id: 1/1 Title: Project OAK MAIN BRD V0.1

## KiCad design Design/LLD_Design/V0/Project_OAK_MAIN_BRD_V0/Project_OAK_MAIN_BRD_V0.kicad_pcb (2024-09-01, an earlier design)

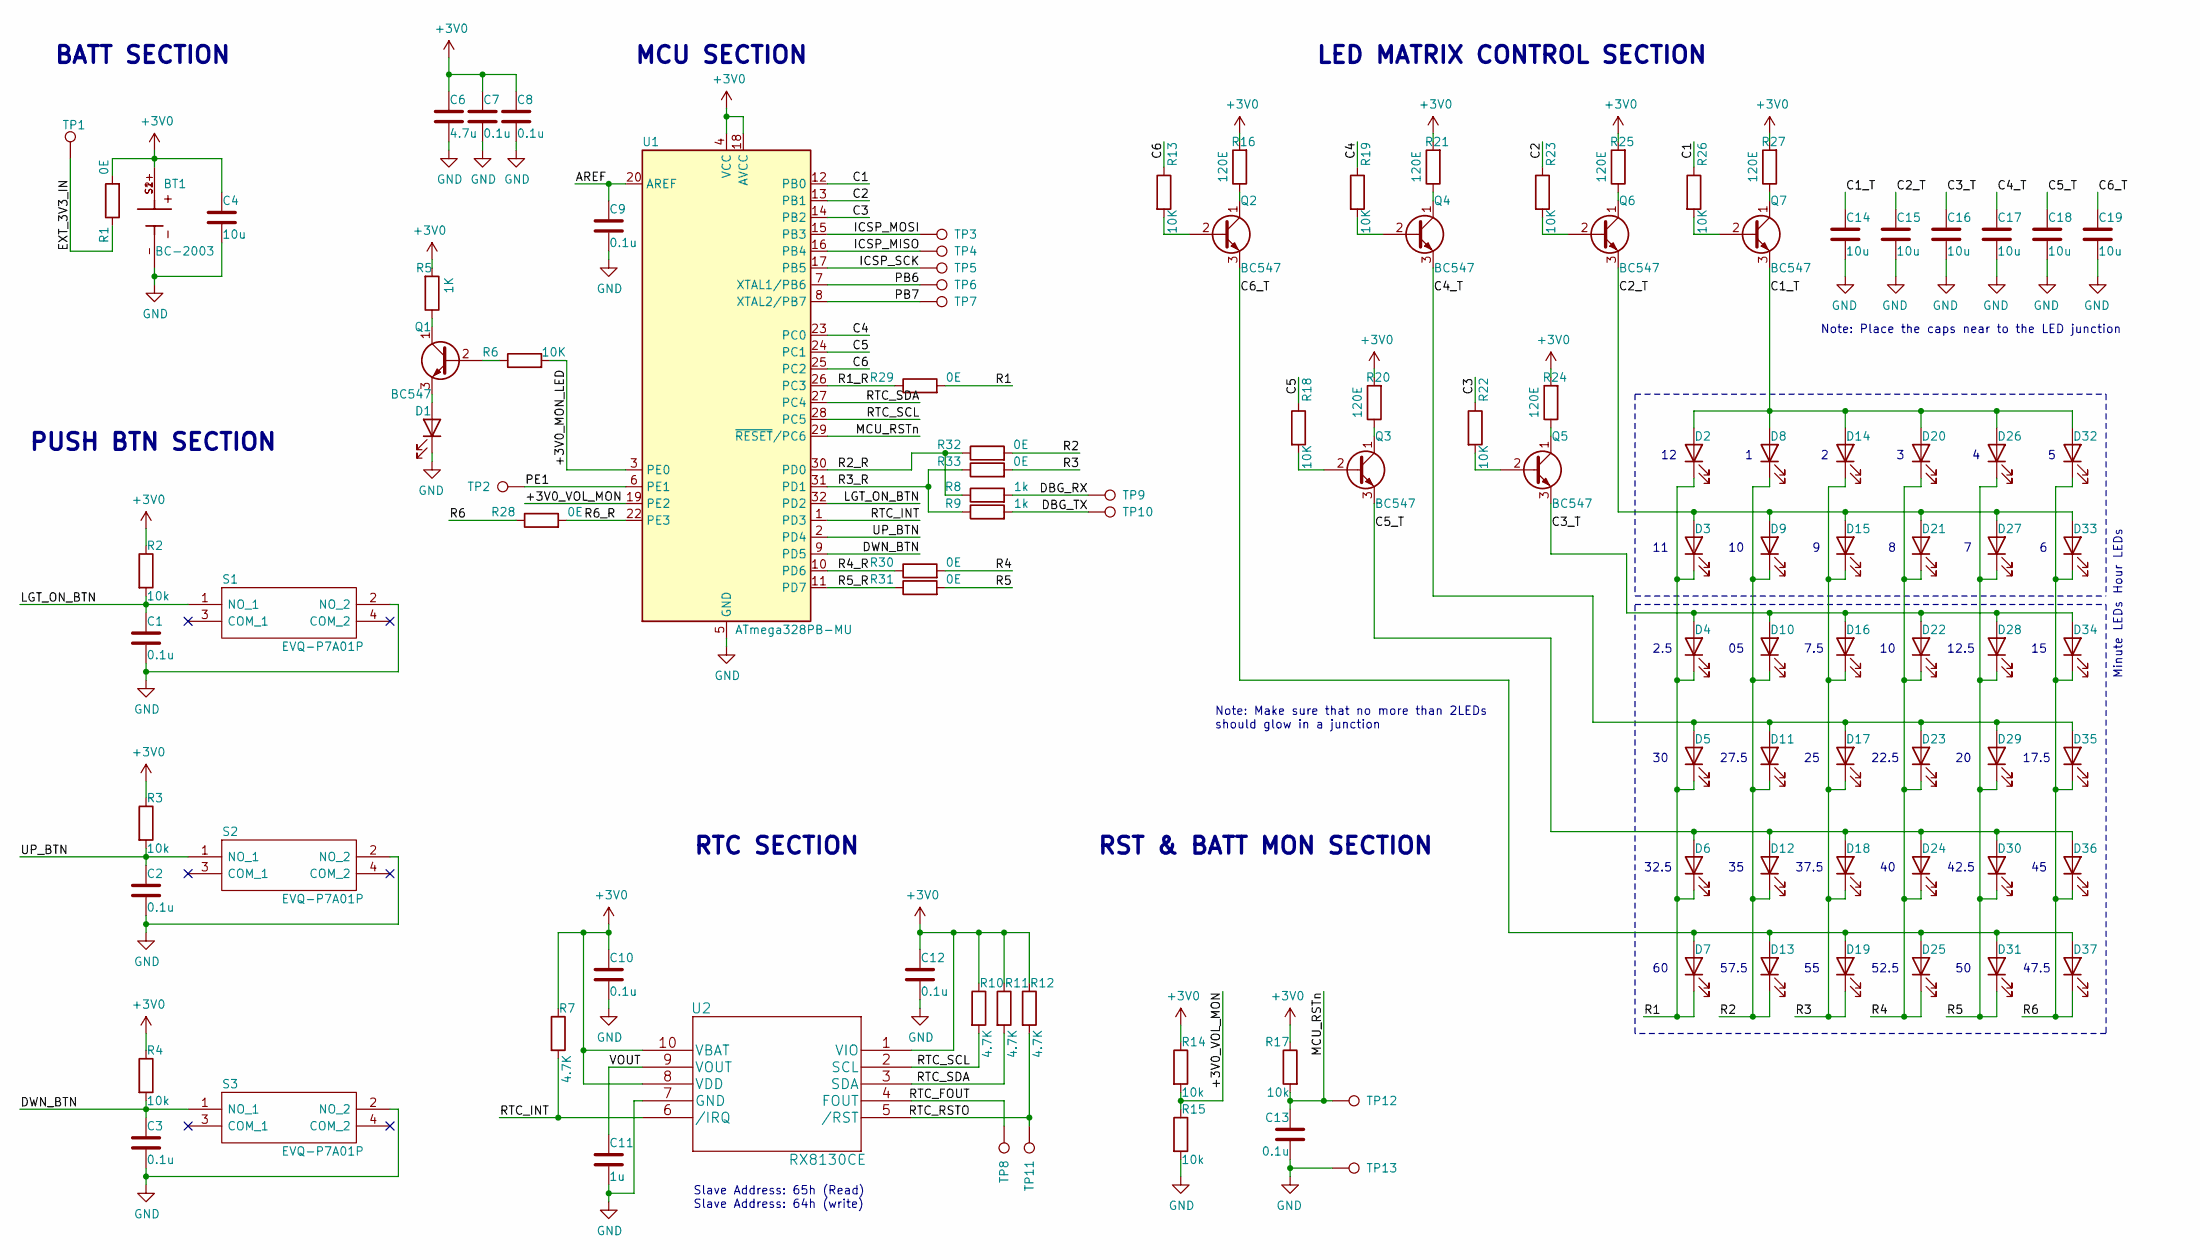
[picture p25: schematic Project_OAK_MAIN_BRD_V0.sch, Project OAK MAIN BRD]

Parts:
BT1: BC-2003; BAT_BC-2003
C1, C2, C3, C7, C8, C9, C10, C12, C13: 0.1u; C_0402_1005Metric
C4, C14, C15, C16, C17, C18, C19: 10u; C_0402_1005Metric
C6: 4.7u; C_0402_1005Metric
C11: 1u; C_0402_1005Metric
D1, D2, D3, D4, D5, D6, D7, D8, D9, D10, D11, D12, D13, D14, D15, D16, D17, D18, D19, D20, D21, D22, D23, D24, D25, D26, D27, D28, D29, D30, D31, D32, D33, D34, D35, D36, D37: LED; LED_0402_1005Metric
Q1, Q2, Q3, Q4, Q5, Q6, Q7: BC547; SOT-23
R1, R28, R29, R30, R31, R32, R33: 0E; R_0402_1005Metric
R2, R3, R4, R14, R15, R17: 10k; R_0402_1005Metric
R5: 1K; R_0402_1005Metric
R6, R13, R18, R19, R22, R23, R26: 10K; R_0402_1005Metric
R7, R10, R11, R12: 4.7K; R_0402_1005Metric
R8, R9: 1k; R_0402_1005Metric
R16, R20, R21, R24, R25, R27: 120E; R_0402_1005Metric
S1, S2, S3: EVQ-P7A01P; EVQP7J01P; Manufacturer_Part_Number EVQ-P7A01P; Mouser Part Number 667-EVQP7A01P
TP1, TP2, TP3, TP4, TP5, TP6, TP7, TP8, TP9, TP10, TP11, TP12, TP13: TestPoint; TestPoint_Pad_D1.0mm
U1: ATmega328PB-MU; QFN-32-1EP_5x5mm_P0.5mm_EP3.1x3.1mm
U2: RX8130CE

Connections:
+3V0: BT1.S1+ (+), BT1.S2+ (+), C4.1, C6.1, C7.1, C8.1, C10.1, C12.1, R1.2, R2.1, R3.1, R4.1, R5.2, R7.1, R10.1, R11.1, R12.1, R14.1, R16.2, R17.1, R20.2, R21.2, R24.2, R25.2, R27.2, U1.4 (VCC), U1.18 (AVCC), U2.1 (VIO), U2.8 (VDD), U2.10 (VBAT)
/+3V0_MON_LED: R6.2, U1.3 (PE0)
/+3V0_VOL_MON: R14.2, R15.1, U1.19 (PE2)
/AREF: C9.1, U1.20 (AREF)
/C1: R26.1, U1.12 (PB0)
/C1_T: C14.1, D2.2 (A), D8.2 (A), D14.2 (A), D20.2 (A), D26.2 (A), D32.2 (A), Q7.3 (E)
/C2: R23.1, U1.13 (PB1)
/C2_T: C15.1, D3.2 (A), D9.2 (A), D15.2 (A), D21.2 (A), D27.2 (A), D33.2 (A), Q6.3 (E)
/C3: R22.1, U1.14 (PB2)
/C3_T: C16.1, D4.2 (A), D10.2 (A), D16.2 (A), D22.2 (A), D28.2 (A), D34.2 (A), Q5.3 (E)
/C4: R19.1, U1.23 (PC0)
/C4_T: C17.1, D5.2 (A), D11.2 (A), D17.2 (A), D23.2 (A), D29.2 (A), D35.2 (A), Q4.3 (E)
/C5: R18.1, U1.24 (PC1)
/C5_T: C18.1, D6.2 (A), D12.2 (A), D18.2 (A), D24.2 (A), D30.2 (A), D36.2 (A), Q3.3 (E)
/C6: R13.1, U1.25 (PC2)
/C6_T: C19.1, D7.2 (A), D13.2 (A), D19.2 (A), D25.2 (A), D31.2 (A), D37.2 (A), Q2.3 (E)
/DBG_RX: R8.2, TP9.1
/DBG_TX: R9.2, TP10.1
/DWN_BTN: C3.1, R4.2, S3.1 (NO_1), U1.9 (PD5)
/EXT_3V3_IN: R1.1, TP1.1
/ICSP_MISO: TP4.1, U1.16 (PB4)
/ICSP_MOSI: TP3.1, U1.15 (PB3)
/ICSP_SCK: TP5.1, U1.17 (PB5)
/LGT_ON_BTN: C1.1, R2.2, S1.1 (NO_1), U1.32 (PD2)
/MCU_RSTn: C13.1, R17.2, TP12.1, U1.29 (~RESET~/PC6)
/PB6: TP6.1, U1.7 (XTAL1/PB6)
/PB7: TP7.1, U1.8 (XTAL2/PB7)
/PE1: TP2.1, U1.6 (PE1)
/R1: D2.1 (K), D3.1 (K), D4.1 (K), D5.1 (K), D6.1 (K), D7.1 (K), R29.2
/R1_R: R29.1, U1.26 (PC3)
/R2: D8.1 (K), D9.1 (K), D10.1 (K), D11.1 (K), D12.1 (K), D13.1 (K), R32.2
/R2_R: R8.1, R32.1, U1.30 (PD0)
/R3: D14.1 (K), D15.1 (K), D16.1 (K), D17.1 (K), D18.1 (K), D19.1 (K), R33.2
/R3_R: R9.1, R33.1, U1.31 (PD1)
/R4: D20.1 (K), D21.1 (K), D22.1 (K), D23.1 (K), D24.1 (K), D25.1 (K), R30.2
/R4_R: R30.1, U1.10 (PD6)
/R5: D26.1 (K), D27.1 (K), D28.1 (K), D29.1 (K), D30.1 (K), D31.1 (K), R31.2
/R5_R: R31.1, U1.11 (PD7)
/R6: D32.1 (K), D33.1 (K), D34.1 (K), D35.1 (K), D36.1 (K), D37.1 (K), R28.1
/R6_R: R28.2, U1.22 (PE3)
/RTC_FOUT: TP8.1, U2.4 (FOUT)
/RTC_INT: R7.2, U1.1 (PD3), U2.6 (/IRQ)
/RTC_RSTO: R12.2, TP11.1, U2.5 (/RST)
/RTC_SCL: R10.2, U1.28 (PC5), U2.2 (SCL)
/RTC_SDA: R11.2, U1.27 (PC4), U2.3 (SDA)
/UP_BTN: C2.1, R3.2, S2.1 (NO_1), U1.2 (PD4)
/VOUT: C11.1, U2.9 (VOUT)
GND: BT1.-, C1.2, C2.2, C3.2, C4.2, C6.2, C7.2, C8.2, C9.2, C10.2, C11.2, C12.2, C13.2, C14.2, C15.2, C16.2, C17.2, C18.2, C19.2, D1.1 (K), R15.2, S1.2 (NO_2), S2.2 (NO_2), S3.2 (NO_2), TP13.1, U1.5 (GND), U1.21 (GND), U1.33 (GND), U2.7 (GND)
unnamed: D1.2 (A), Q1.3 (E)
unnamed: Q1.1 (C), R5.1
unnamed: Q1.2 (B), R6.1
unnamed: Q2.1 (C), R16.1
unnamed: Q2.2 (B), R13.2
unnamed: Q3.1 (C), R20.1
unnamed: Q3.2 (B), R18.2
unnamed: Q4.1 (C), R21.1
unnamed: Q4.2 (B), R19.2
unnamed: Q5.1 (C), R24.1
unnamed: Q5.2 (B), R22.2
unnamed: Q6.1 (C), R25.1
unnamed: Q6.2 (B), R23.2
unnamed: Q7.1 (C), R27.1
unnamed: Q7.2 (B), R26.2

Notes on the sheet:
RTC SECTION
PUSH BTN SECTION
BATT SECTION
MCU SECTION
Slave Address: 65h (Read) Slave Address: 64h (write)
LED MATRIX CONTROL SECTION
RST & BATT MON SECTION
Note: Place the caps near to the LED junction
Note: Make sure that no more than 2LEDs should glow in a junction
Hour LEDs
Minute LEDs
2.5
7.5
12.5
17.5
22.5
27.5
32.5
37.5
42.5
47.5
52.5
57.5

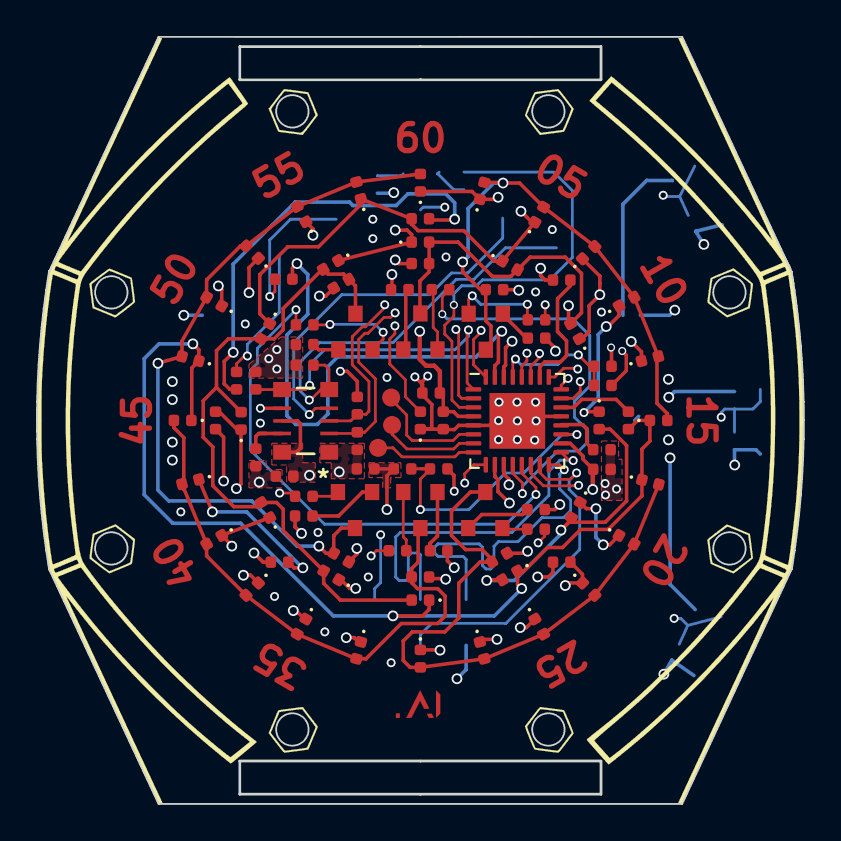
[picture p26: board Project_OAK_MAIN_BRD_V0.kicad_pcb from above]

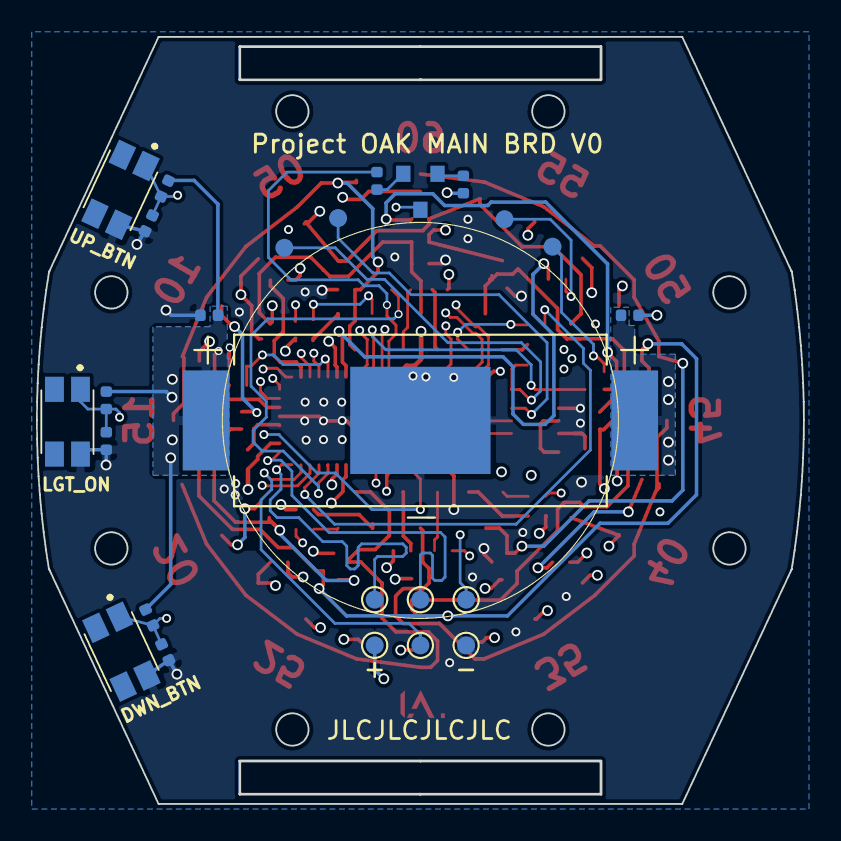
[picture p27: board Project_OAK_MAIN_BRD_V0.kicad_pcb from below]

Board: 6 copper layers, 42.6 x 42.6 mm, 114 parts (25 on the bottom side), 63 nets.

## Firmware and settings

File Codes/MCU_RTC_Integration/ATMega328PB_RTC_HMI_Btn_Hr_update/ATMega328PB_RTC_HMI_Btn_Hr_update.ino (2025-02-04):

/**********************************************************************************************************
  Simple AVR sketch demonstrate the interface of RTC sensor RV-8263-C7 with ATMega328PB. This code is to
  execute Hour, Minute & MI functions of the RTC sensor and outputs the data using on-board LEDs (visulization).
  Post power on, MCU goes to sleep and wakes up on interrupt generated either by the RTC sensor (every minute)
  or with button press (PWR BTN). based on the button press duration, specific set of actions are performed.
  If button press short (50ms), the device outputs RTC sensor data by lighting up the LEDs (Time Indication)
  and goes back to sleep. If button press long (1000ms), the device wakes up from pwr-down mode and stays
  in active state by blinking all the LEDs onboard (100ms). This allows user to update Time by pressing
  UP & DWN button to adjust Hour time respectively. Once updated time, the device is put back to sleep 
  by short pressing the PWR button.

  Sketch uses "OakLedMatrix" lib which takes care of mapping LED pins to their respective Hr/Min positions
  Sketch uses "RV-8263-C7" lib which takes care of interface between MCU and RV-8263-C7 RTC sensor

  Here are the list of registers that are modified / accessed in this program

  |Register|         |Function|      |Bit7|  |Bit6|  |Bit5|  |Bit4|  |Bit3|  |Bit2|  |Bit1|  |Bit0|
  |                                                                                               |
  |  01h   |         |Control2|      |AIE |  | AF |  | MI |  |HMI |  | TF |  | FD|   | FD |  | FD |
  |  04h   |         |Seconds|       | OS |  | 40 |  | 20 |  | 10 |  | 8  |  | 4 |   | 2 |   | 1  |
  |  05h   |         |minutes|       | X  |  | 40 |  | 20 |  | 10 |  | 8  |  | 4 |   | 2 |   | 1  |
  |  06h   |          |Hours|        | X  |  | X  |  |AMPM|  | 10 |  | 8  |  | 4 |   | 2 |   | 1  |
  |  07h   |          |Date|         | X  |  | X  |  | 20 |  | 10 |  | 8  |  | 4 |   | 2 |   | 1  |
  |  08h   |         |Weekday|       | X  |  | X  |  | X  |  | X  |  | X  |  | 4 |   | 2 |   | 1  |
  |  09h   |          |Month|        | X  |  | X  |  | X  |  | 10 |  | 8  |  | 4 |   | 2 |   | 1  |
  |  0Ah   |          |Year|         | 80 |  | 40 |  | 20 |  | 10 |  | 8  |  | 4 |   | 2 |   | 1  |
  |  11h   |       |Timer Mode|      | X  |  | X  |  | X  |  | TD |  | TD |  |TE |   |TIE|  |TI_TP|
**********************************************************************************************************/

#include <avr/io.h>
#include <avr/sleep.h>
#include <util/delay.h>
#include <RV-8263-C7.h>
#include <OakLedMatrix.h>
#include <math.h>

#define HMI_INTERRUPT_PIN PD3   // RTC interrupt (INT1)
#define PWR_BUTTON_PIN PD2   // Push button interrupt (INT0)
#define UP_BUTTON_PIN PD4       // Button to increase value
#define DWN_BUTTON_PIN PD5      // Button to decrease value
#define SHORT_PRESS_DURATION 50   // Duration in milliseconds
#define LONG_PRESS_DURATION 1000  // Duration in milliseconds

volatile bool wakeUpFlag = false;      // Interrupt flag to indicate wake-up event
volatile uint16_t pressDuration = 0;   // Stores button press timestamp
volatile bool buttonPressed = false;   // Flag for button press event
volatile uint8_t stayAwake = false;    // Flag to keep MCU awake
volatile bool inUpdateMode = false; // Flag to track update mode

void setup() {
  initMatrix();
  initRTC();
  _delay_ms(1000);

  // Configure RTC for Half-Minute Interrupt (HMI)
  writeRegister(0x01, 0b00100000); // Set periodic interrupt to Minute
  writeRegister(0x11, 0b00011001); // Enable periodic interrupt

  // Configure PD3 (INT1) for RTC interrupt (falling edge)
  DDRD &= ~(1 << HMI_INTERRUPT_PIN); // Set PD3 as input
  PORTD |= (1 << HMI_INTERRUPT_PIN); // Enable pull-up resistor on PD3
  EICRA |= (1 << ISC11); // Falling edge triggers INT1
  EICRA &= ~(1 << ISC10);
  EIMSK |= (1 << INT1);  // Enable INT1 interrupt

  // Configure PD2 (INT0) for push-button wake-up (falling edge)
  DDRD &= ~(1 << PWR_BUTTON_PIN); // Set PD2 as input
  PORTD |= (1 << PWR_BUTTON_PIN); // Enable pull-up resistor on PD3
  EICRA |= (1 << ISC01);
  EICRA &= ~(1 << ISC00);
  EIMSK |= (1 << INT0);  // Enable INT0 interrupt

  // Configure navigation buttons (PD4, PD5) as inputs with pull-ups
  DDRD &= ~((1 << UP_BUTTON_PIN) | (1 << DWN_BUTTON_PIN));
  PORTD |= (1 << UP_BUTTON_PIN) | (1 << DWN_BUTTON_PIN);

  sei(); // Enable global interrupts
}

// Interrupt Service Routine (ISR) for RTC wake-up on PD3 (INT1)
ISR(INT1_vect) {
  wakeUpFlag = true;
}

// Interrupt Service Routine (ISR) for push-button wake-up on PD2 (INT0)
ISR(INT0_vect) {
  buttonPressed = true;  // Flag to handle the button press in the main loop
}

void loop() {
  if (buttonPressed) {
    _delay_ms(50);  // Basic debounce delay
    buttonPressed = false;

    // Measure press duration
    pressDuration = 0;
    while (!(PIND & (1 << PWR_BUTTON_PIN))) {
      _delay_ms(10);  // Increment duration in 10ms steps
      pressDuration += 10;
      if (pressDuration >= LONG_PRESS_DURATION) {
        break;  // Stop counting if long press is detected
      }
    }

    if (pressDuration >= LONG_PRESS_DURATION) {
      stayAwake = true;  // Set stayAwake, preventing sleep
      functionLongPress();
      enterUpdateMode();
    } else if (pressDuration >= SHORT_PRESS_DURATION) {
      stayAwake = false;  // Allow sleep
      functionShortPress();
    }
  }

  if (wakeUpFlag) {
    wakeUpFlag = false;
    displayTime();
  }

  if (!stayAwake && !inUpdateMode) {
    enterSleepMode();
  }
}

// Function to enter power-down sleep mode
void enterSleepMode() {
  set_sleep_mode(SLEEP_MODE_PWR_DOWN); // Power-down mode
  sleep_enable(); // Enable sleep mode
  sleep_cpu(); // Enter sleep mode (wait for interrupt)
  sleep_disable(); // Disable sleep after waking up
}

// Function to get RTC time and display it using LED matrix
void displayTime() {
  uint8_t hours, minutes, seconds, date, day, month, year;
  const char period[3];

  getTime(hours, minutes, seconds, date, day, month, year, period);

  // Convert minutes to corresponding LED index (2.5 min per LED)
  uint8_t minuteMap = round(minutes / 2.5);

  // Show hour and minute time for 1 second
  uint16_t displayDuration = 500 / 10;  // 100ms per toggle for 0.5 second

  for (uint16_t i = 0; i < displayDuration; i++) {
    LedClockHourTime(hours);
    _delay_ms(5);
    LedClockMinuteTime(minuteMap);
    _delay_ms(5);
  }

  deactivateLedMatrix(); // Turn off LEDs
}

// === Short Press Function ===
void functionShortPress() {
  displayTime();
}

// === Long Press Function ===
void functionLongPress() {
  activateLedMatrixAll();
  _delay_ms(100);
  deactivateLedMatrix();
  _delay_ms(100);
}

// === LED Navigation Mode for Setting Hour ===
void enterUpdateMode() {
  inUpdateMode = true;
  uint8_t newHour = 12; // Default hour selection
  uint8_t up_button_state, dwn_button_state, pwr_button_state;
  uint8_t last_button_state = 0;

  while (inUpdateMode) {
    // Read button states
    up_button_state = PIND & (1 << UP_BUTTON_PIN);
    dwn_button_state = PIND & (1 << DWN_BUTTON_PIN);
    pwr_button_state = PIND & (1 << PWR_BUTTON_PIN);

    // If any button was pressed
    if ((up_button_state == 0 && last_button_state != 0) ||
        (dwn_button_state == 0 && last_button_state != 0) ||
        (pwr_button_state == 0 && last_button_state != 0)) {

      _delay_ms(50); // Debounce delay

      // Increase hour
      if ((PIND & (1 << UP_BUTTON_PIN)) == 0) {
        newHour = (newHour == 12) ? 1 : newHour + 1;
      }

      // Decrease hour
      if ((PIND & (1 << DWN_BUTTON_PIN)) == 0) {
        newHour = (newHour == 1) ? 12 : newHour - 1;
      }

      // Confirm and update RTC
      if ((PIND & (1 << PWR_BUTTON_PIN)) == 0) {
        updateRTC(newHour);
        inUpdateMode = false;
        return;
      }
    }

    // Display hour LED navigation
    LedClockHourTime(newHour);
    _delay_ms(100); // Small delay to improve responsiveness

    // Store last button state
    last_button_state = up_button_state | dwn_button_state | pwr_button_state;
  }
}

// === Update RTC with New Hour ===
void updateRTC(uint8_t newHour) {
  uint8_t nowHour, nowMinutes, nowSeconds, nowDate, nowDay, nowMonth, nowYear;
  const char nowPeriod[3];

  getTime(nowHour, nowMinutes, nowSeconds, nowDate, nowDay, nowMonth, nowYear, nowPeriod);
  updateTime(newHour, nowMinutes, nowSeconds, nowDate, nowDay, nowMonth, nowYear, nowPeriod);
}

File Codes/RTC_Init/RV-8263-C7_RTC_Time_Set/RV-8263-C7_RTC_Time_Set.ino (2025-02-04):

/**********************************************************************************************************
  Simple AVR sketch demonstrate the interface of RTC sensor RV-8263-C7 with ATMega328PB. This code is to
  execute Hour, Minute & Seconds, date, day, month & year functions of the RTC sensor. During the start-up,
  the intended time values are updated to their respective registers. Post that, RTC keeps updating the
  registers and sends the data to the MCU at 1s interval. The data from MCU is then sent out through serial
  interface. The LEDs on the main baord blinks for 100ms on every successful data sent out through serial
  interface.

  Sketch uses "OakLedMatrix" lib which takes care of mapping LED pins to their respective Hr/Min positions

  |Register|         |Function|      |Bit7|  |Bit6|  |Bit5|  |Bit4|  |Bit3|  |Bit2|  |Bit1|  |Bit0|
  |                                                                                               |
  |  00h   |         |Control1|      |Test|  | SR |  |STOP|  | SR |  | SR |  |CIE|   |12_24| | CAP|
  |  04h   |         |Seconds|       | OS |  | 40 |  | 20 |  | 10 |  | 8  |  | 4 |   | 2 |   | 1  |
  |  05h   |         |minutes|       | X  |  | 40 |  | 20 |  | 10 |  | 8  |  | 4 |   | 2 |   | 1  |
  |  06h   |          |Hours|        | X  |  | X  |  |AMPM|  | 10 |  | 8  |  | 4 |   | 2 |   | 1  |
  |  07h   |          |Date|         | X  |  | X  |  | 20 |  | 10 |  | 8  |  | 4 |   | 2 |   | 1  |
  |  08h   |         |Weekday|       | X  |  | X  |  | X  |  | X  |  | X  |  | 4 |   | 2 |   | 1  |
  |  09h   |          |Month|        | X  |  | X  |  | X  |  | 10 |  | 8  |  | 4 |   | 2 |   | 1  |
  |  0Ah   |          |Year|         | 80 |  | 40 |  | 20 |  | 10 |  | 8  |  | 4 |   | 2 |   | 1  |
**********************************************************************************************************/

#include <Wire.h>
#include "OakLedMatrix.h"
#define RTC_ADDRESS 0x51  // I2C address of the RTC

// Function to write a value to a specific RTC register in binary
void writeRegister(uint8_t reg, uint8_t value) {
  Wire.beginTransmission(RTC_ADDRESS); // Start communication with RTC
  Wire.write(reg);                     // Set the register pointer
  Wire.write(value);                   // Write the value to the register
  Wire.endTransmission();              // End transmission
}

// Function to read a value from a specific RTC register in binary
uint8_t readRegister(uint8_t reg) {
  Wire.beginTransmission(RTC_ADDRESS); // Start communication with RTC
  Wire.write(reg);                     // Set the register pointer
  Wire.endTransmission();              // End transmission

  Wire.requestFrom(RTC_ADDRESS, 1);    // Request 1 byte from the register
  while (Wire.available() == 0);       // Wait for the data to arrive
  return Wire.read();                  // Read and return the value
}

// Function to convert BCD to Decimal
uint8_t BCDtoDecimal(uint8_t bcdValue, uint8_t bitMask) {
  bcdValue &= bitMask;                // Mask to consider only the required bits
  return ((bcdValue >> 4) * 10) + (bcdValue & 0x0F); // Convert BCD to decimal
}

// ISR for Transmit Complete Interrupt
ISR(USART_TX_vect) {
  activateLedMatrixAll(); // Toggle the LED
  _delay_ms(100);
  deactivateLedMatrix();
}

void setup() {
  Wire.begin();             // Initialize I2C
  Serial.begin(9600);       // Initialize Serial Communication

  // Initialize OakLedMatrix
  initMatrix();

  // Set RTC registers with binary values
  writeRegister(0x00, 0b00000010); // 12 hour mode

  // Update the Hour, Minute & Seconds value once
    writeRegister(0x04, 0b10110000); // Seconds: 30 (binary)
    writeRegister(0x05, 0b00110000); // Minutes: 30 (binary)
    writeRegister(0x06, 0b00101000); // Hours: 8 (binary, 8 PM)
    writeRegister(0x07, 0b00011001); // Date: 19
    writeRegister(0x08, 0b00000111); // Weekday: 6
    writeRegister(0x09, 0b00000001); // Month: 1
    writeRegister(0x0A, 0b00100101); // Year: 25

  //Serial.println("RTC registers set individually in binary.");

  // Enable TX Complete Interrupt
  UCSR0B |= (1 << TXCIE0);

  // Enable global interrupts
  sei();
}

void loop() {
  uint8_t seconds, minutes, hours, Date, Day, Month, Year;
  uint8_t secondsDec, minutesDec, hoursDec, dateDec, dayDec, monthDec, yearDec;

  // Read individual RTC registers in binary
  seconds = readRegister(0x04); // Read seconds register
  minutes = readRegister(0x05); // Read minutes register
  hours = readRegister(0x06);   // Read hours register
  Date = readRegister(0x07);    // Read Date register
  Day = readRegister(0x08);    // Read Day register
  Month = readRegister(0x09);  // Read Month register
  Year = readRegister(0x0A);   // Read Year register

  // Convert BCD to Decimal considering only the valid bits
  secondsDec = BCDtoDecimal(seconds, 0x7F); // Mask 7 bits for seconds
  minutesDec = BCDtoDecimal(minutes, 0xFF); // Full 8 bits for minutes
  hoursDec = BCDtoDecimal(hours, 0x1F);     // Mask 5 bits for hours
  dateDec = BCDtoDecimal(Date, 0x3F);       // Mask 6 bits for hours
  dayDec = BCDtoDecimal(Day, 0x07);         // Mask 3 bits for hours
  monthDec = BCDtoDecimal(Month, 0x1F);     // Mask 5 bits for month
  yearDec = BCDtoDecimal(Year, 0xFF);       // Full 8 bits for year

  Serial.println("------------------------------------------------------");

  // Print binary data to Serial Monitor
  Serial.print("Current Time (Binary): ");
  Serial.print("Hours: ");
  Serial.print(hours, BIN);
  Serial.print(", Minutes: ");
  Serial.print(minutes, BIN);
  Serial.print(", Seconds: ");
  Serial.print(seconds, BIN);
  Serial.print(", Date: ");
  Serial.print(Date, BIN);
  Serial.print(", Day: ");
  Serial.print(Day, BIN);
  Serial.print(", Month: ");
  Serial.print(Month, BIN);
  Serial.print(", Year: ");
  Serial.println(Year, BIN);

  // Print time to Serial Monitor
  Serial.print("Current Time: ");
  if (hoursDec < 10) Serial.print('0');
  Serial.print(hoursDec);
  Serial.print(":");
  if (minutesDec < 10) Serial.print('0');
  Serial.print(minutesDec);
  Serial.print(":");
  if (secondsDec < 10) Serial.print('0');
  Serial.println(secondsDec);

  Serial.print("Current Date: ");
  if (dateDec < 10) Serial.print('0');
  Serial.println(dateDec);
  Serial.print("Current Day: ");
  if (dayDec < 10) Serial.print('0');
  Serial.println(dayDec);
  Serial.print("Current Month: ");
  if (monthDec < 10) Serial.print('0');
  Serial.println(monthDec);
  Serial.print("Current Year: ");
  if (yearDec < 10) Serial.print('0');
  Serial.println(yearDec);
  Serial.println("------------------------------------------------------");

  delay(1000);  // Wait for 1 second before reading again
}

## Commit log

2024-09-01 Initial Commit
    These are the basic codes that is used to perform basic bring-up on Project_OAK_MAIN_BRD_V0.1 board.
2024-09-01 Project Initial Commit
    [74CBTLV3257BQ,115.stp, 74CBTLV3257BQ115.PcbLib, 74CBTLV3257BQ_115.SchLib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]
2024-09-04 Added RTC sensor Initialization codes
2024-09-11 Updated README.md with Steps to program the Main Board
2024-09-15 Updated Blink code, SCH comments & added LED mapping details
    [Project_OAK_MAIN_BRD_V0.1.sch, Project_OAK_MCU_Pinouts.xlsx]
2024-09-16 Added LED loop code
2024-11-25 removed LED_loop & added OakLedMartix test codes
2025-02-10 added random led animation to the library
2025-07-06 rearranged design files based on versions and added mechanical DXF files
    [PROJECT_OAK_BOT_STRAP.dxf, PROJECT_OAK_TOP_LED_CAVITY.dxf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]
2025-08-02 removed 3D test folder
    [Project_OAK_MAIN_BRD_V0.1_RTC_3D_test.kicad_pcb, Project_OAK_MAIN_BRD_V0.1_RTC_3D_test.sch]

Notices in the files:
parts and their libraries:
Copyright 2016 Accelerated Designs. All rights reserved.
